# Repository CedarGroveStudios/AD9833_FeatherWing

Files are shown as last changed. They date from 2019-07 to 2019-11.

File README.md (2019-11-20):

### _A precision waveform generator FeatherWing_
# AD9833_FeatherWing

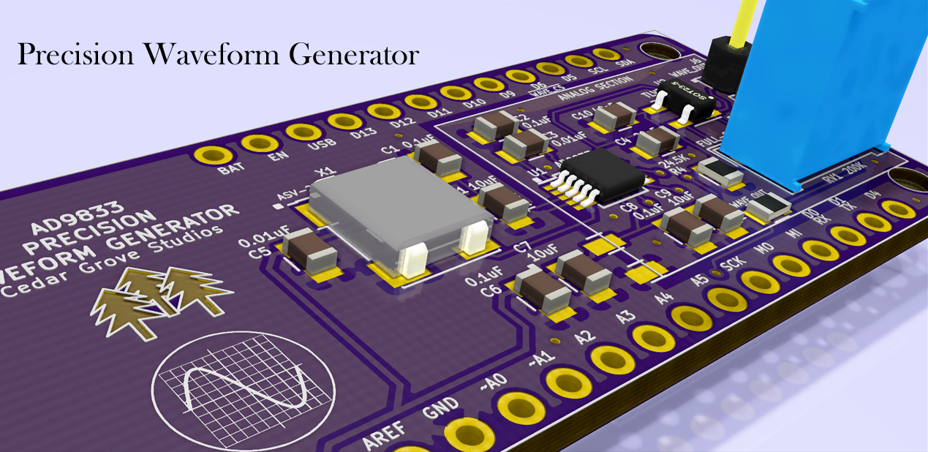
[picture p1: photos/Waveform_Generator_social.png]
Image of Module


## Overview
The AD9833 Precision Waveform Generator FeatherWing is an Adafruit Feather-compatible module. The Waveform Generator produces an op-amp buffered sine, triangle, or square wave output with a practical frequency range of 0.5Hz to 100KHz with 0.1Hz resolution.  
  * Frequency accuracy and stability is determined by the on-board 25MHz +/- 100ppm crystal oscillator (Abracon ASV-25.000MHZ-E-T).  
  * Waveform Generator control is via the Feather SPI bus; chip select is provided by the D6 GPIO pin.  
  *	Output signal peak-to-peak amplitude is adjustable with a maximum unipolar output of slightly less than 3.3 volts.  
  *	Output can optionally be connected to the A2 analog input pin via an on-board jumper for real-time output signal monitoring.  
  *	The wing derives its power from the host Feather's 3.3V power.  

The AD9833 Precision Waveform Generator FeatherWing was tested with a Feather M4 Express using CircuitPython version 4.1.0 rc-1. Example sweep generator code is provided in the repository (sweep example video: https://youtu.be/O1vMfLoCWzg). 

OSH Park project: https://oshpark.com/shared_projects/al6aPN0u

Refer to the Analog Devices' AD9833 Waveform Generator data sheet for device control protocol details.

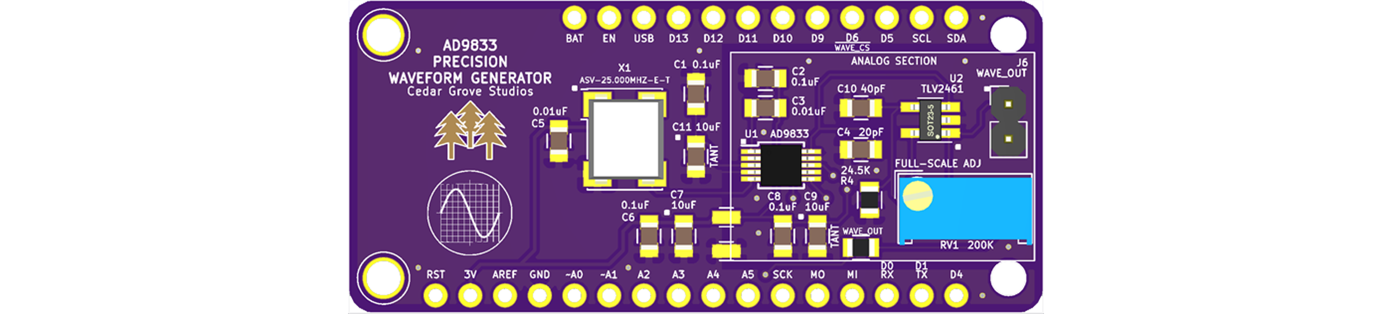
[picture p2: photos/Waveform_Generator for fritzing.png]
Fritzing Image


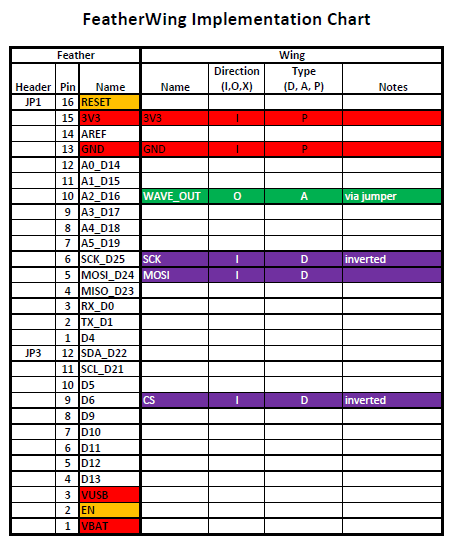
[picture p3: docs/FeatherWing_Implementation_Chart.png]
FeatherWing Implementation Chart


## Primary Project Objectives
1)	Generate useful waveforms in the audio frequency range
  a.	Highly accurate and stable absolute frequency: ±0.5Hz, 1000ppm  
  b.	Moderately accurate waveform shape: 8-bit minimum  
  c.	Fixed 3.0 volt peak-to-peak output, centered at 1.5 volts  
2)	Implement with CircuitPython code
3)	Increase SPI communications knowledge
4)	Improve SMD soldering skills
5)	Improve conceptual knowledge  
  a.	SPI communications  
  b.	Swept frequency control  
  c.	Digital signal generation  
  d.	CircuitPython device drivers  
  e.	ADSR envelope modulation (optional)  
6)	Fabricate physical equipment  
  a.	Workbench fixed and swept signal generator  
  b.	MIDI and CV controlled LFO and audio frequency Eurorack oscillator module  

## Deliverables
1)	Custom FeatherWing PCB, M4 Express pinout
2)	FeatherWing Implementation Chart
3)	CircuitPython device driver
4)	CircuitPython examples and test code
5)	KiCAD schematic and board layout with Gerber code
6)	OSH Park public shared project page
7)	GitHub public repository page
8)	Project description and report
9)	Workbench signal generator
10)	Eurorack module
## Concepts Learned
1)	Solder paste stencil was essential for successful SOT-23 and MSOP-10 component soldering
2)	10-bit waveform accuracy will be sufficient for most anticipated uses
3)	Waveform output amplitude was very stable from 0 to 250kHz
4)	Output buffer op-amp gain-bandwidth product limit contributes significantly to high frequency roll-off but also smooths the digital feedthrough components of the waveform
5)	The low peak of the waveform only reaches +150mV not 0V as anticipated
6)	Waveform generator DAC output filtering capacitance was listed incorrectly in the datasheet example; value used for manufacturer testing was correct
7)	Separate analog ground on the PCB helped to reduce analog output digital noise
8)	ADSR envelope generation will require additional circuitry (see https://github.com/CedarGroveStudios/AD9833_ADSR_FeatherWing for the full discussion of tests)
9)	Output frequency change throughput of the CircuitPython example code (using the cedargrove_AD9833 library) is approximately 450usec, allowing for frequency sweep steps and modulation rates of > 2k changes(steps) per sec
10)	CircuitPython driver code was simpler to create than anticipated  
  a.	CircuitPython SPI communications techniques are well-documented  
  b.	Command register protocol was thoroughly explained in the device datasheet  
  c.	Non-typical clock polarity was the only issue to overcome  
## Next Steps
  * Finish the ADSR envelope generation tests and incorporate additional components in the v02 PCB design
  *	Replace the existing op-amp with higher gain-bandwidth version
  *	Consider a FeatherWing-sized dual-output version
  *	Incorporate the knowledge and experience gained in this project with the design of an Arbitrary Waveform Generator FeatherWing

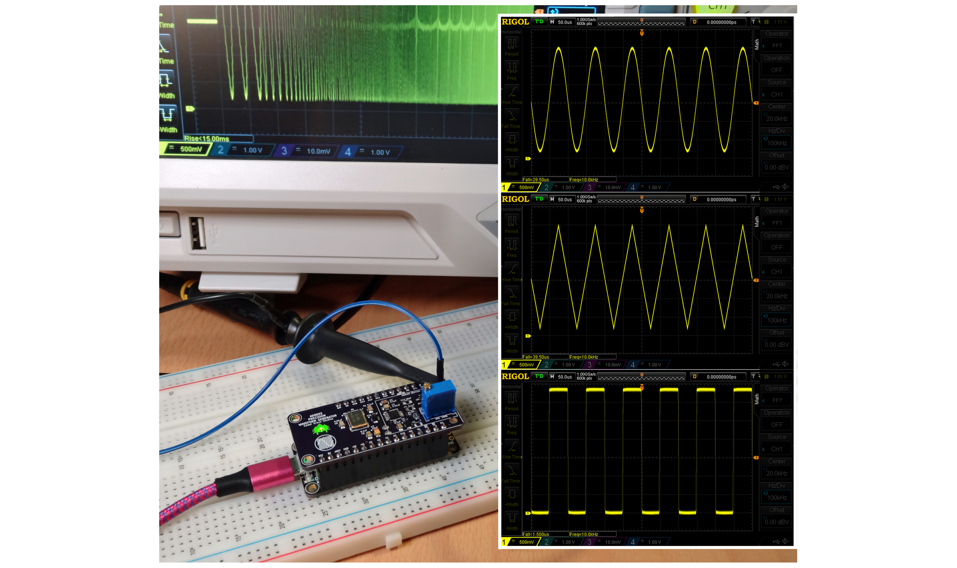
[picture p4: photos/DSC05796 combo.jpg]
Image of Test Setup


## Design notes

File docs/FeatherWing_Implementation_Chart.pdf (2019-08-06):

Feather | Wing
Header | Pin | Name | Name | Direction (I,O,X) | Type (D, A, P) | Notes
JP1 | 16 | RESET
| 15 | 3V3 | 3V3 | I | P
| 14 AREF
| 13 | GND | GND | I | P
| 12 A0_D14
| 11 A1_D15
| 10 | A2_D16 | WAVE_OUT | O | A | via jumper
| 9 A3_D17
| 8 A4_D18
| 7 A5_D19
| 6 | SCK_D25 | SCK | I | D | inverted
| 5 | MOSI_D24 | MOSI | I | D
| 4 MISO_D23
| 3 RX_D0
| 2 TX_D1
| 1 D4
JP3 | 12 | SDA_D22
| 11 SCL_D21
| 10 D5
| 9 | D6 | CS | I | D | inverted
| 8 D9
| 7 D10
| 6 D11
| 5 D12
| 4 D13
| 3 VUSB
| 2 EN
| 1 VBAT

## FeatherWing Implementation Chart

8/6/2019 3:16 PM | FeatherWing_Implementation_Chart.xlsx FeatherWing Impl Chart | Page 1 of 1

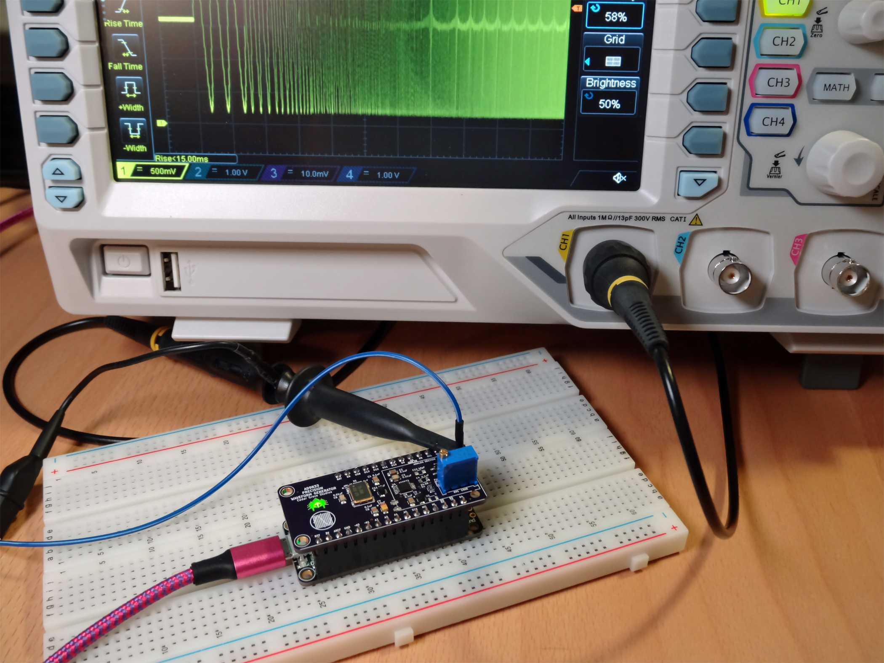
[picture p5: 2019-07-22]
photos/DSC05796a.jpg

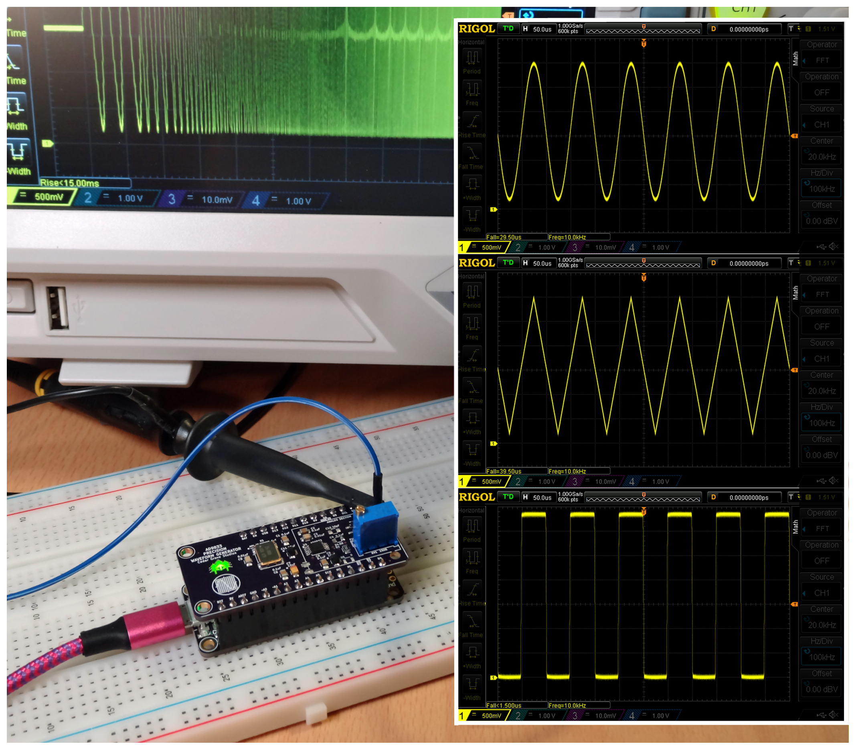
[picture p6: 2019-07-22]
photos/DSC05796 combo orig.jpg

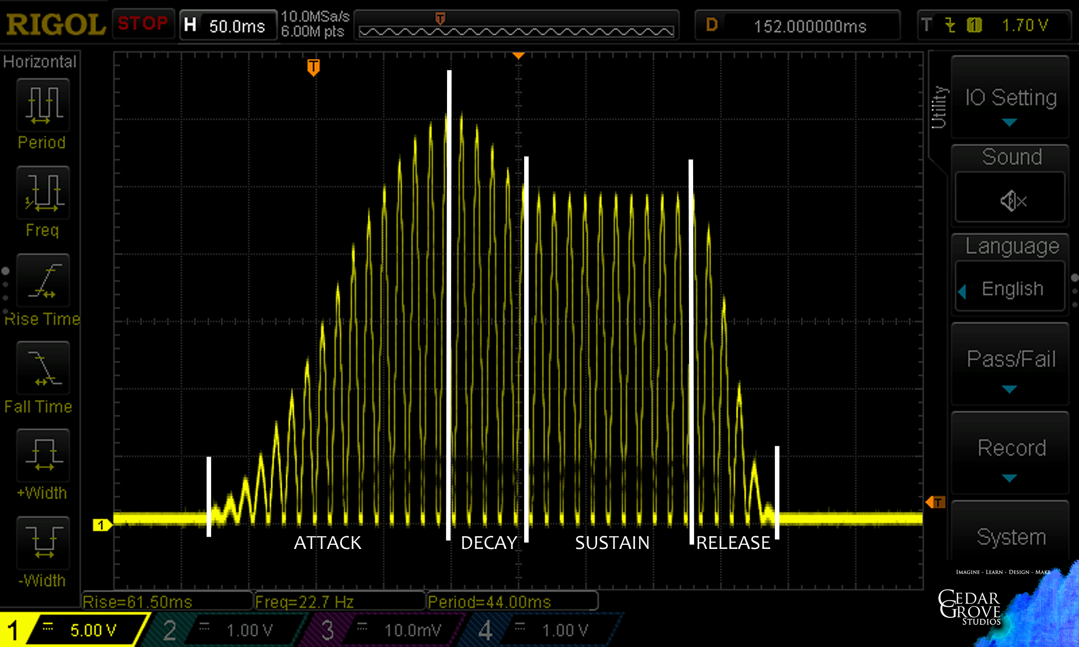
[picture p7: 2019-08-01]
photos/smooth ADSR.png

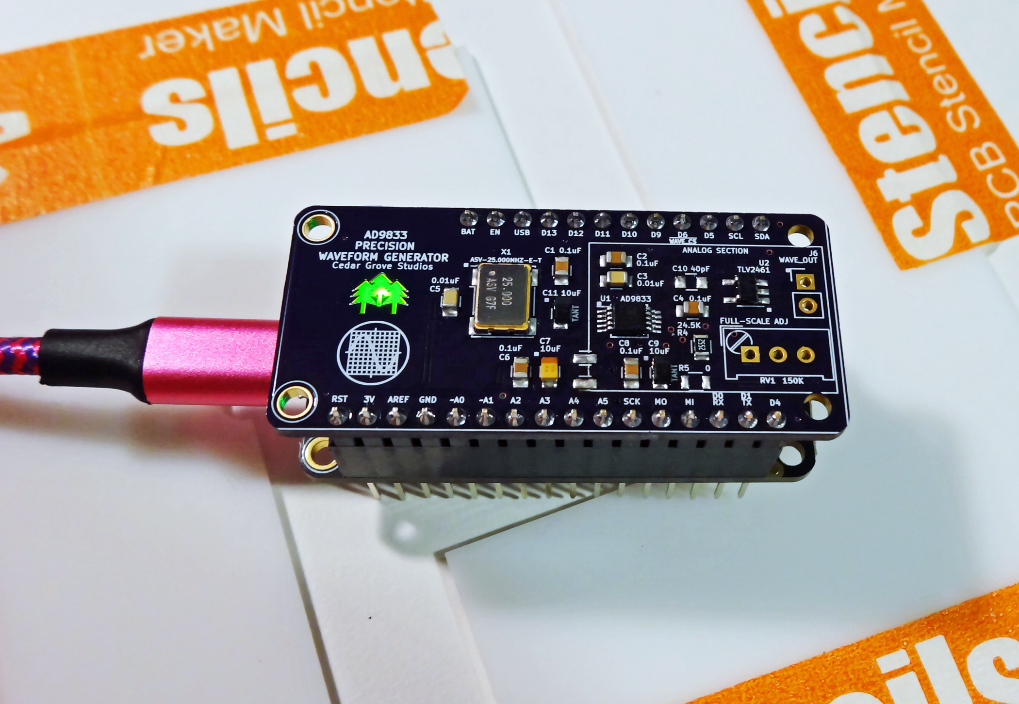
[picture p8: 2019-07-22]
photos/DSC05719a lores.jpg

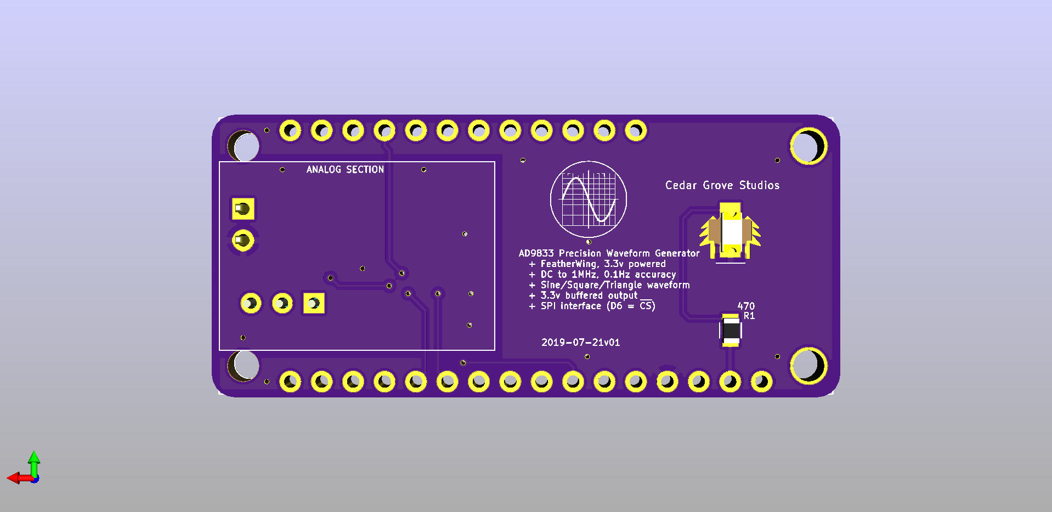
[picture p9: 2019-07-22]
photos/Waveform_Generator bot.png

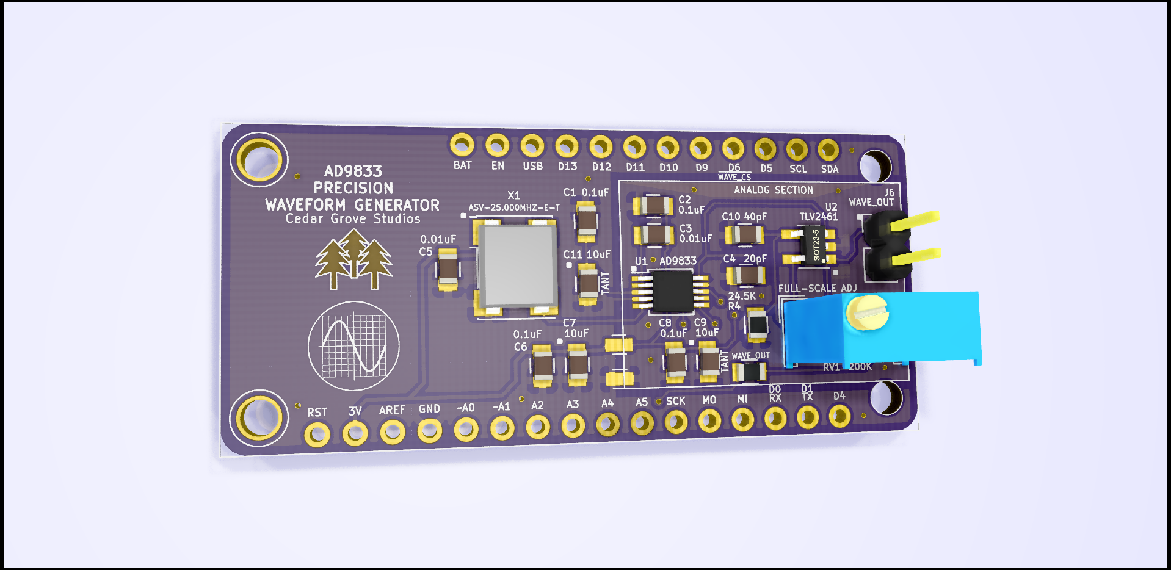
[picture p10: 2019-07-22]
photos/Waveform_Generator glamour.png

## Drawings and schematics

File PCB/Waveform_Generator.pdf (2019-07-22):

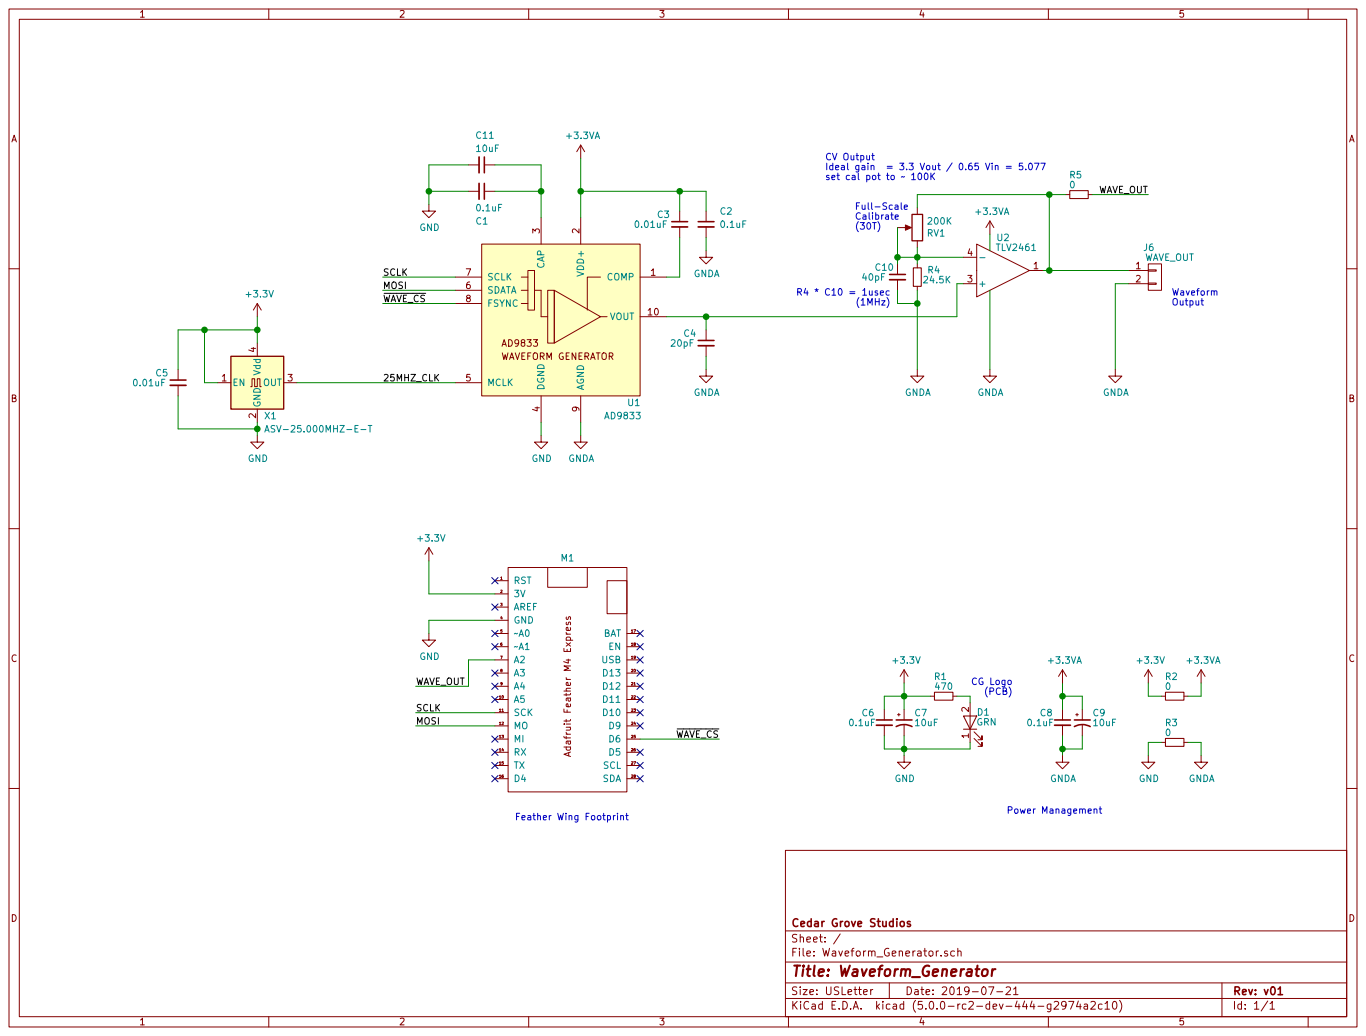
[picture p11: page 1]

CV Output
Ideal gain = 3.3 Vout / 0.65 Vin = 5.077
set cal pot to 100K

9U1 AD9833 Adafruit Feather M4 Express RST 1 A5 10 SCK 11 MO 12 MI 13 RX 14 TX 15 D4 16 BAT 17 EN 18 USB 19 3V 2 D13 20 D12 21 D11 22 D10 23 D9 24 D6 25 D5 26 SCL 27 SDA 28 AREF 3 GND 4 A0 5 A1 6 A2 7 A3 8 A4 9 M1 SCLK MOSI WAVE_CS

4 MCLK 5 SDATA 6 SCLK 7 FSYNC 8 AGND

File: Waveform_Generator.sch Sheet: / Cedar Grove StudiosGND

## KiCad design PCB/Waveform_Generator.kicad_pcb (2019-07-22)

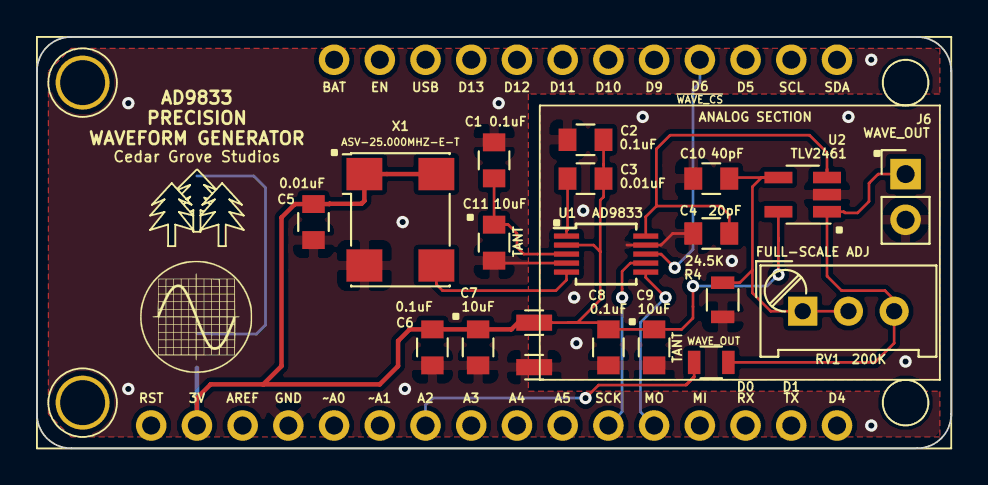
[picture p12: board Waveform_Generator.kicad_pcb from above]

Board: 2 copper layers, 50.8 x 22.9 mm, 23 parts (1 on the bottom side), 15 nets.

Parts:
C1, C2, C6, C8: 0.1uF; C_0805
C3, C5: 0.01uF; C_0805
C4: 20pF; C_0805
C7, C9, C11: 10uF; C_0805
C10: 40pF; C_0805
D1: GRN; Cedar_Grove_logo_lighted
J6: WAVE_OUT; Pin_Header_Straight_1x02_Pitch2.54mm
M1: Feather_M4_Express; Adafruit_Feather_M4_Express_bare
R1: 470; R_0805
R2, R3: 0; NetTie_0603
R4: 24.5K; R_0805
R5: 0; R_0805
RV1: 200K; Potentiometer_Trimmer_Bourns_PV36W
U1: AD9833; MSOP-10_3x3mm_Pitch0.5mm
U2: TLV2461; SOT-23-5_HandSoldering
X1: ASV-25.000MHZ-E-T; Oscillator_SMD_Abracon_ASV-4pin_7.0x5.1mm

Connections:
+3.3VA: C2.1, C3.1, C8.1, C9.1, R2.1, U1.2, U2.5
+3V3: C5.1, C6.1, C7.1, M1.2, R1.2, R2.2, X1.1, X1.4
/25MHZ_CLK: U1.5, X1.3
/MOSI: M1.12, U1.6
/SCLK: M1.11, U1.7
/WAVE_OUT: M1.7, R5.1
/~WAVE_CS: M1.25, U1.8
GND: C1.2, C5.2, C6.2, C7.2, C11.2, D1.1, M1.4, R3.2, U1.4, X1.2
GNDA: C2.2, C4.2, C8.2, C9.2, C10.2, J6.2, R3.1, R4.1, U1.9, U2.2
unnamed: C1.1, C11.1, U1.3
unnamed: C3.2, U1.1
unnamed: C4.1, U1.10, U2.3
unnamed: C10.1, R4.2, RV1.1, RV1.2, U2.4
unnamed: D1.2, R1.1
unnamed: J6.1, R5.2, RV1.3, U2.1

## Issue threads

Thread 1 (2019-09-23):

'AD9833' class object has no attribute '_pause'

phrogger, 2019-09-23:
I am running your driver "cedargrove_ad9833.py", not the "cedargrove_ad9833.mpy"

When running a simple test program, that just creates an AD9833 object, then sets the frequency to a fixed value and starts the wave generator, I get the following error.

Traceback (most recent call last):
  File "main.py", line 21, in <module>
  File "cedargrove_ad9833.py", line 185, in update_freq
  File "cedargrove_ad9833.py", line 226, in update_control_reg
AttributeError: 'AD9833' object has no attribute '_pause'

Examining the python source for the AD9833 class indicates that there is no attribute "self._pause"
Adding a line "self._pause = False" to the def __init__ resolves everything.

---
I bought some AD9833 featherwing wave_generator boards from Oshpark, assembled one, and everything works as expected.  Thanks for designing the board and driver code and releasing the information.
--- Graham

==

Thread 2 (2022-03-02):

pass in SPI bus, use contribution bundle release

ladyada, 2022-03-02:
hiya, we have a person who is using this library with issues
https://forums.adafruit.com/viewtopic.php?f=62&t=188798
and a few things would help debug the library:

- like other libraries that use SPI, you should not be creating the SPI device, it should be passed in as an argument
- instead of generating mpy's that will not stay up to date, submit the library to the bundle https://github.com/adafruit/CircuitPython_Community_Bundle and do proper releases on version changes

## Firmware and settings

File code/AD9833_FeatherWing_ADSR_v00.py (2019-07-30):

# AD9833_FeatherWing_MIDI_in_v00.py
# 2019-07-28 Cedar Grove Studios
# Simple MIDI voice module using Cedar Grove AD9833 Precision Waveform
#     Generator FeatherWing and Cedar Grove Classic MIDI FeatherWing
#
#      cedargrove_AD9833_FeatherWing library
#      cedargrove_MIDI_util library
#
# Tested with Adafruit Feather M4 Express and CircuitPython 4.1.0 rc-1.

# establish class instance with chip_select pin D6
import cedargrove_AD9833_FeatherWing as AD9833
wave_gen = AD9833.WaveGenerator(select="D6")

import board
import busio
import time
import adafruit_midi
import usb_midi

# use one of M4's DACs to control output amplitude
# connect output of AD9833 wing to Feather AREF (after removing AREF to 3.3v trace)
from analogio import AnalogOut
dac_out = AnalogOut(board.A0)
dac_out.value = 0  # start a zero amplitude

from cedargrove_MIDI_util import *

from adafruit_midi.timing_clock            import TimingClock
from adafruit_midi.channel_pressure        import ChannelPressure
from adafruit_midi.control_change          import ControlChange
from adafruit_midi.note_off                import NoteOff
from adafruit_midi.note_on                 import NoteOn
from adafruit_midi.pitch_bend              import PitchBend
from adafruit_midi.polyphonic_key_pressure import PolyphonicKeyPressure
from adafruit_midi.program_change          import ProgramChange
from adafruit_midi.start                   import Start
from adafruit_midi.stop                    import Stop
from adafruit_midi.system_exclusive        import SystemExclusive
from adafruit_midi.midi_message            import MIDIUnknownEvent

UART = busio.UART(board.TX, board.RX, baudrate=31250, timeout=0.001)
midi = adafruit_midi.MIDI(midi_in=UART, midi_out=UART, in_channel=0, out_channel=0)

# *** Helpers ***

def amplitude_stepper(start, end, period):  # step from start to end amplitude over time period
    if start < end:
        dac_out.value = int(65535 * start)
        for amplitude in range(int(start*100), int(end*100)):
            if amplitude != 0:
                dac_out.value = int(65535 * (amplitude/100))
            else:
                dac_out.value = 0
            time.sleep(period/100)
    elif start > end:
        dac_out.value = int(65535 * start)
        for amplitude in range(int(start*100), int(end*100), -1):
            if amplitude != 0:
                dac_out.value = int(65535 * (amplitude/100))
            else:
                dac_out.value = 0
            time.sleep(period/100)
    else:  # start = end
        dac_out.value = int(65535 * start)
        time.sleep(period)

def wave_ADSr(a=(1.0,0), d=(1.0,0), s=(1.0,0)):
    amplitude_stepper(0, a[0], a[1])  # attack
    amplitude_stepper(a[0], d[0], d[1])  # decay
    amplitude_stepper(d[0], s[0], s[1])  # sustain

def wave_adsR(s=(1.0,0), r=(0.0,0)):
    amplitude_stepper(s[0], r[0], r[1])  # release

# *** Main code area ***
print("AD9833_FeatherWing_ADSR_v00.py")
print("Input channel:", midi.in_channel + 1 )

# establish initial parameters
adsr_A  = (1.0, 0.3) # attack level, time
adsr_D  = (0.6, 0.3) # decay level, time
adsr_S  = (0.6, 0.1) # sustain level, time
adsr_R  = (0, 0.5)   # release level, time

t0 = time.monotonic_ns()
tempo = 0
wave_type = "triangle"      # sine, triangle, or square waveform

wave_gen.reset()  # reset and stop the wave generator; reset all registers
wave_gen.wave_type = wave_type  # load the waveform type value
wave_gen.start()

while True:

    msg = midi.receive()

    if msg is not None:
        # midi.send(msg)  # MIDI thru
        if isinstance(msg, NoteOn):
            print("NoteOn : #%02d %s %5.3fHz" % (msg.note, note_lexo(msg.note), note_freq(msg.note)))
            print("     vel   %03d     chan #%02d" %(msg.velocity, msg.channel + 1))
            wave_gen.update_freq(note_freq(msg.note))
            if msg.velocity > 0: wave_ADSr(adsr_A, adsr_D, adsr_S)
            else: wave_adsR(adsr_S, adsr_R)

        elif isinstance(msg, NoteOff):
            print("NoteOff: #%02d %s %5.3fHz" % (msg.note, note_lexo(msg.note), note_freq(msg.note)))
            print("     vel   %03d     chan #%02d" %(msg.velocity, msg.channel + 1))
            wave_adsR(adsr_S, adsr_R)

        elif isinstance(msg, TimingClock):
            t1 = time.monotonic_ns()
            if (t1-t0) != 0:
                tempo = (tempo + (1 / ((t1 - t0) * 24) * 60 * 1e9)) / 2 # simple running average
                print("-- Tick: %03.1f BPM" % tempo)  # compared to previous tick
            t0 = time.monotonic_ns()

        elif isinstance(msg, ChannelPressure):
            print("ChannelPressure: ")
            print("     press %03d     chan #%02d" %(msg.pressure, msg.channel + 1))
            '''wave_type = "sine"
            if msg.pressure > 24: wave_type = "triangle"
            if msg.pressure > 80: wave_type = "square"
            wave_gen.wave_type = wave_type
            wave_gen.start()'''

        elif isinstance(msg, ControlChange):
            print("ControlChange: ctrl #%03d  %s" % (msg.control, cc_decoder(msg.control)))
            print("     value %03d     chan #%02d" %(msg.value, msg.channel + 1))

        elif isinstance(msg, PitchBend):
            print("PitchBend: ")
            print("     bend  %05d   chan #%02d" %(msg.pitch_bend, msg.channel + 1))

        elif isinstance(msg, PolyphonicKeyPressure):
            print("PolyphonicKeyPressure:")
            print("          #%02d %s %5.3fHz" % (msg.note, note_lexo(msg.note), note_freq(msg.note)))
            print("     press %03d     chan #%02d" %(msg.pressure, msg.channel + 1))

        elif isinstance(msg, ProgramChange):
            print("ProgramChange:")
            print("     patch %03d     chan #%02d" %(msg.patch, msg.channel + 1))

        elif isinstance(msg, (Start, Stop)): print("-- %s --" % str(type(msg))[8:-2])

        elif isinstance(msg, SystemExclusive):
            print("SystemExclusive:  ID= ", msg.manufacturer_id,
                ", data= ", msg.data)
            print("--------------------")

        elif isinstance(msg, MIDIUnknownEvent):
            # Message are only known if they are imported
            print("Unknown MIDI event status ", msg.status)

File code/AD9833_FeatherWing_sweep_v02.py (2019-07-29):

# AD9833_FeatherWing_sweep_v02.py
# 2019-07-27 Cedar Grove Studios
# Fixed or swept frequency generator example. Update "initial parameters"
# section for required functionality.
#
# uses cedargrove_ad9833 driver
# Tested with Adafruit Feather M4 Express and CircuitPython 4.1.0 rc-1.

import time

import cedargrove_ad9833
wave_gen = cedargrove_ad9833.AD9833()

# *** Helpers ***

# *** Main code area ***
print("AD9833_FeatherWing_sweep_v02.py")

# establish initial parameters
begin_freq = 20        # fixed or sweep starting frequency (Hz)
end_freq = 5000         # sweep ending frequency (Hz)
inc_freq = 10           # sweep freqency step size (Hz)
periods_per_step = 30   # number of waveform periods to hold (non-linear mode)
sweep_mode = "fixed"    # fixed (10ms per step) or non-linear sweep hold timing
freq_mode = "sweep"     # fixed or sweep frequency
wave_type = "sine"      # sine, triangle, or square waveform

while True:
    wave_gen.reset()
    wave_gen.wave_type = wave_type
    wave_gen.start()

    if freq_mode == "sweep":
        wave_gen.start()

        for i in range(begin_freq, end_freq, inc_freq):
            # print("sweep: frequency =", i)
            wave_gen.update_freq(i)

            if sweep_mode == "non-linear":
                time.sleep(periods_per_step * (1 / i))  # pause for x periods at the specified frequency
            else:
                time.sleep(0.010)  # 10msec fixed hold time per step
    else:
        # output a fixed frequency for 10 seconds
        # print("fixed: frequency =", begin_freq)
        wave_gen.update_freq(begin_freq)
        wave_gen.start()
        time.sleep(10)  # 10sec fixed hold time

    wave_gen.stop()  # stop wave generator

    time.sleep(1)  # wait a second then do it all over again

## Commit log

2019-07-22 inital repo load
    [Waveform_Generator-B.Cu.gbl, Waveform_Generator-B.Mask.gbs, Waveform_Generator-B.Paste.gbp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]
2019-07-29 eliminate potential for startup noise
    [AD9833_FeatherWing_simple_sweep_v02.py]
2019-07-29 updated driver class and file naming to align better with Adafruit's
2019-08-01 updated ADSR example to include note velocity and envelop smoothing
2019-08-01 add velocity and portamento
2019-08-06 update featherwing impl chart
    [FeatherWing_Implementation_Chart.xlsx]
2019-08-06 updated documentation and BOM
    [FeatherWing_Implementation_Chart.xlsx, Waveform_Generator_BOM.xlsx]
2019-08-06 update BOM spreadsheet
    [Waveform_Generator_BOM.xlsx]
2019-08-06 add wing impl chart
2019-08-06 update impl chart
    [FeatherWing_Implementation_Chart.xlsx]
2019-08-21 custom schematic symbol for AD9833
2019-08-21 added custom schematic symbol for AD9833
2019-11-02 update BOM and Impl Chart
    [FeatherWing_Implementation_Chart.xlsx, Waveform_Generator_BOM.xlsx]
2021-07-12 update documentation
    [FeatherWing_Implementation_Chart.xlsx, Waveform_Generator_BOM.xlsx]
